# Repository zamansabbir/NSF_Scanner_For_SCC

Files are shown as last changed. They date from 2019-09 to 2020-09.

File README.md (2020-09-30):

#Firmware details presented in flow-chart
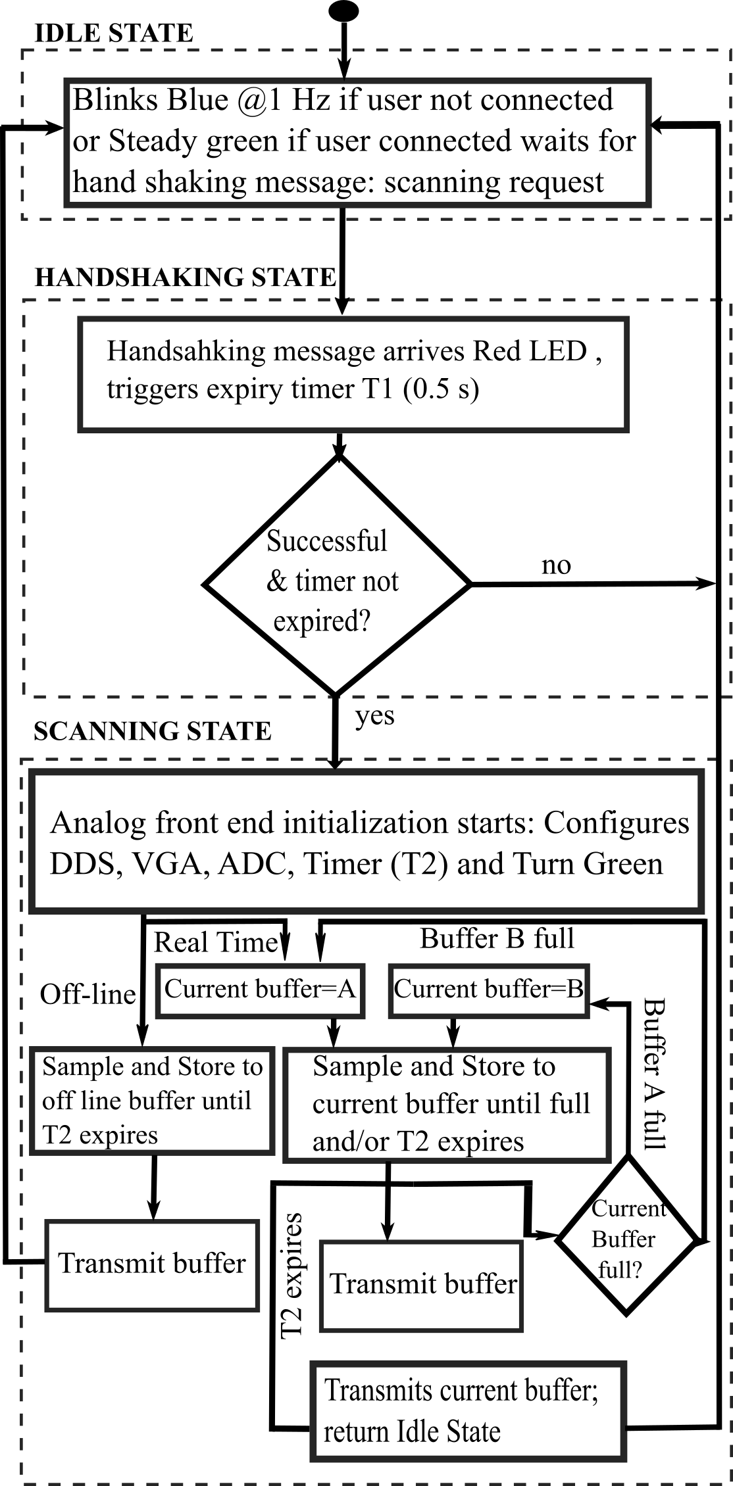
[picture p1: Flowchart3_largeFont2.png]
Flow chart of the Firmware Implemented


#Details of hand-shaking protocol implemented for the project: 
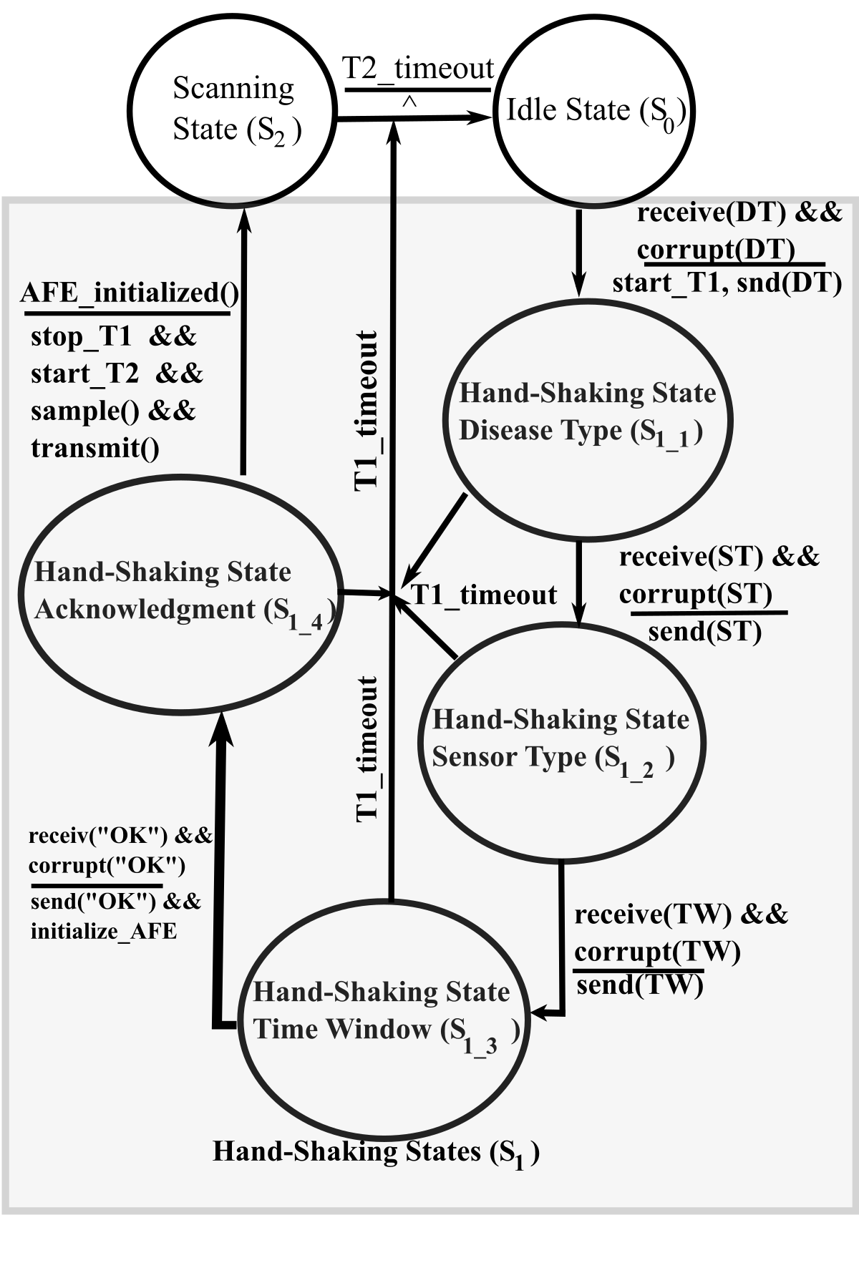
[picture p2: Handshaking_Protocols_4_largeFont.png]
FSM handshaking


.

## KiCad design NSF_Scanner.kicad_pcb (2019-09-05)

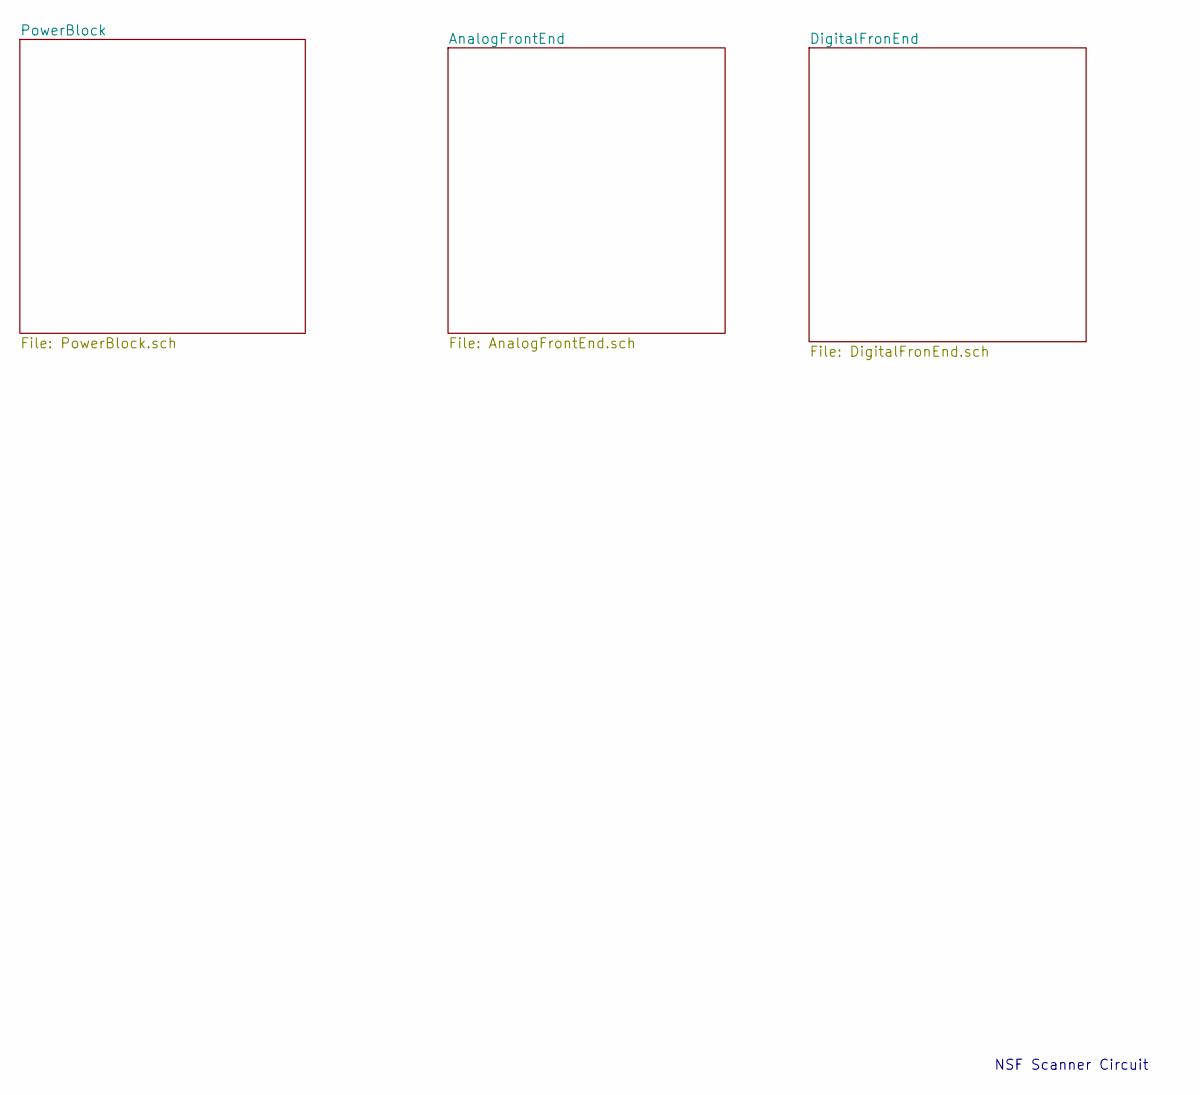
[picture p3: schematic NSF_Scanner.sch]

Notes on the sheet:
NSF Scanner Circuit

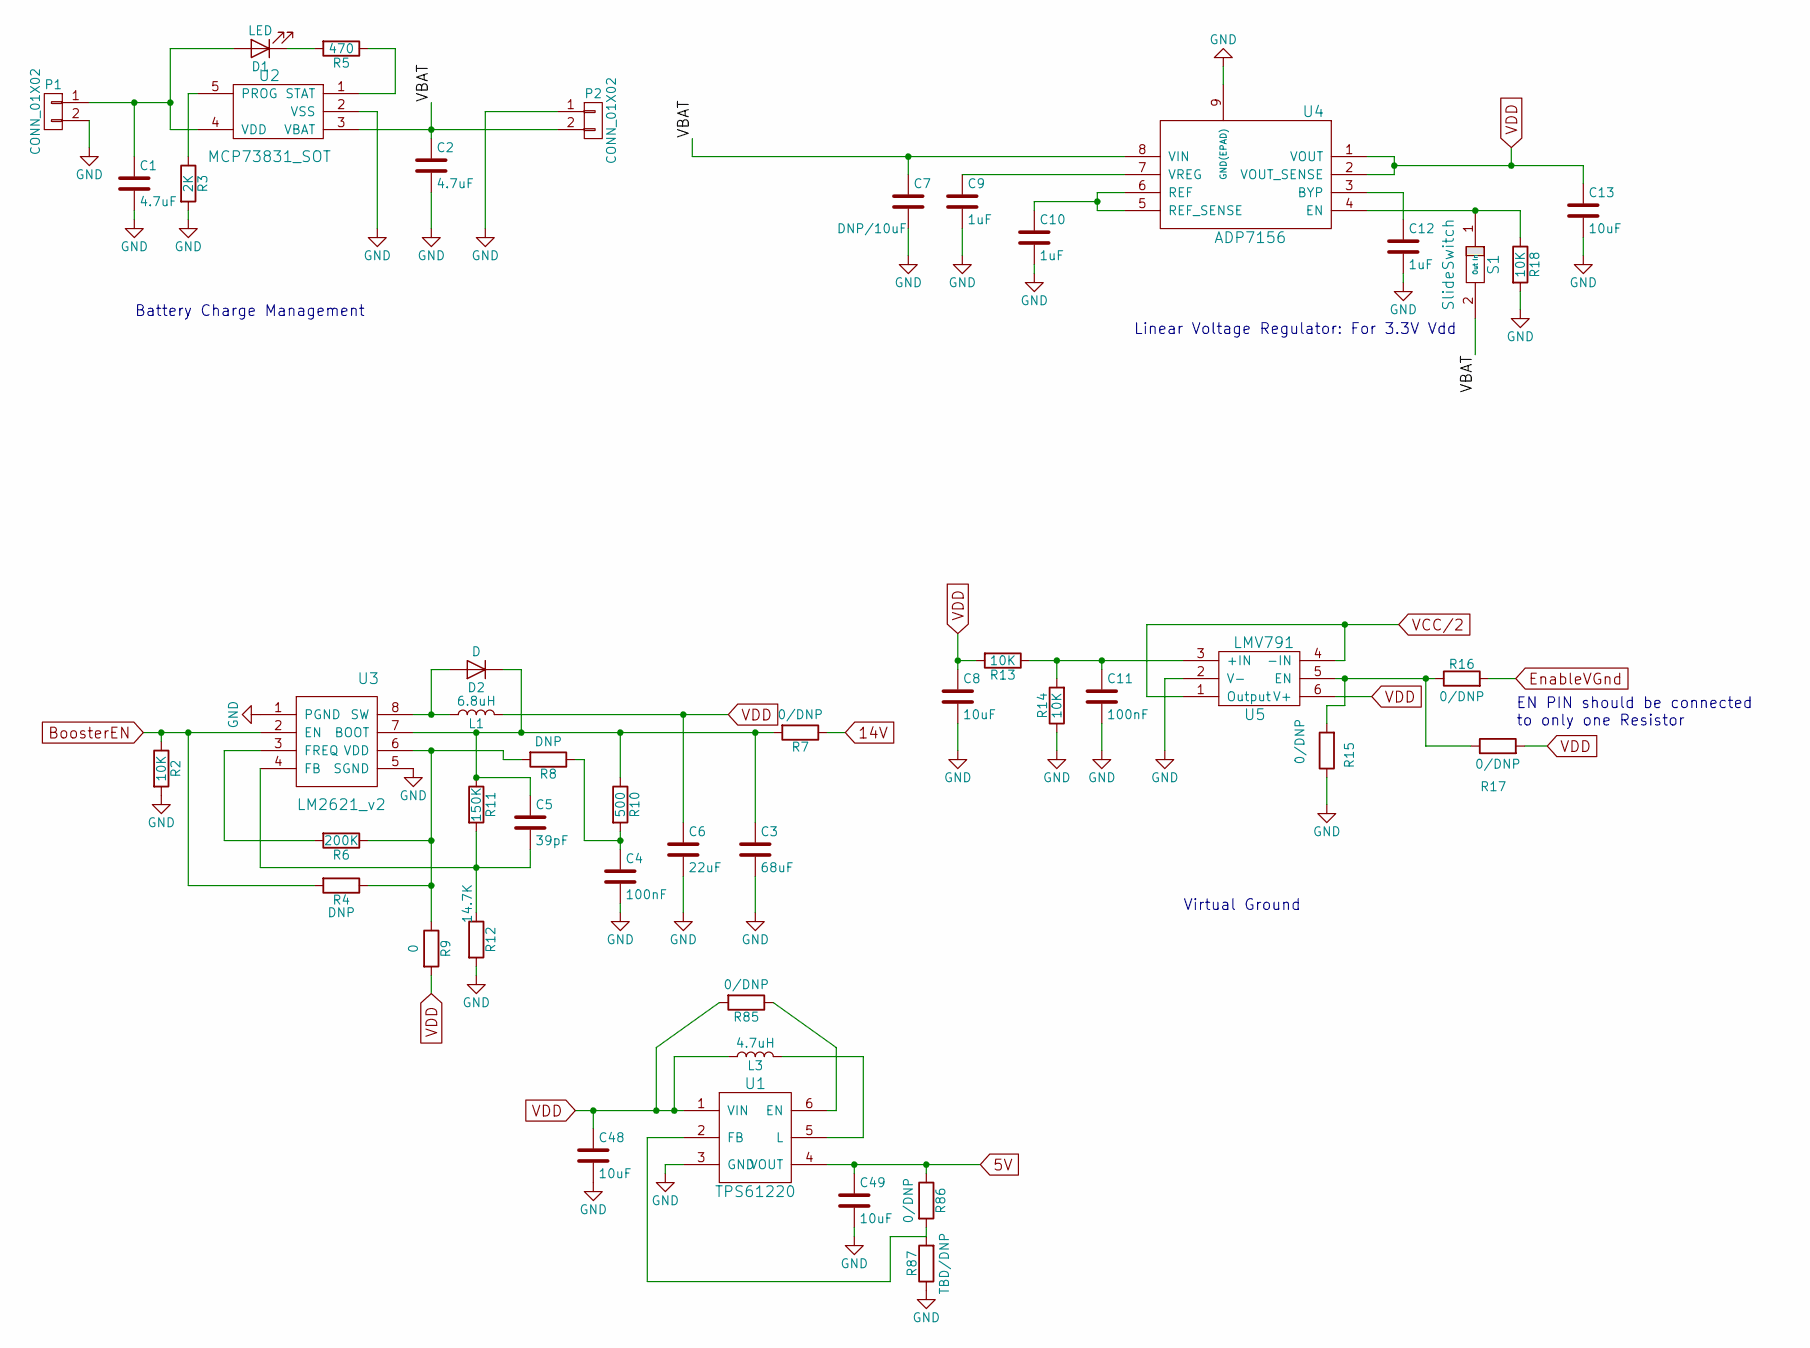
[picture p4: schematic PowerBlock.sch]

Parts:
C1, C2: 4.7uF; C_0603
C3: 68uF; C_1206
C4, C11: 100nF; C_0603
C5: 39pF; C_0603
C6: 22uF; C_0603
C7: DNP/10uF; C_0603
C8, C13, C48, C49: 10uF; C_0603
C9, C10, C12: 1uF; C_0603
D1: LED; LED_0603
D2: D; schottky_power_rectifier
L1: 6.8uH; L_0805_V2
L3: 4.7uH; 4.7uH_v2
P1: CONN_01X02; power_jack
P2: CONN_01X02; bat_con_v2
R2, R13, R14, R18: 10K; R_0603_HandSoldering
R3: 2K; R_0603_HandSoldering
R4, R8: DNP; R_0603_HandSoldering
R5: 470; R_0603_HandSoldering
R6: 200K; R_0603_HandSoldering
R7, R15, R16, R17, R85, R86: 0/DNP; R_0603_HandSoldering
R9: 0; R_0603_HandSoldering
R10: 500; R_0603_HandSoldering
R11: 150K; R_0603_HandSoldering
R12: 14.7K; R_0603_HandSoldering
R87: TBD/DNP; R_0603_HandSoldering
S1: SlideSwitch; SLIDE_SWITCH_V2
U1: TPS61220; TPS61222DCKR
U2: MCP73831_SOT; SOT-23-5_HandSoldering
U3: LM2621_v2
U4: ADP7156; ADP7156_v2
U5: LMV791; LMV791_v2

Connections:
5V: C49.1, R86.1, U1.4 (VOUT); also elsewhere on the board
14V: R7.1; also elsewhere on the board
/PowerBlock/VBAT: C2.1, C7.1, P2.2, S1.2 (Out), U2.3 (VBAT), U4.8 (VIN)
BoosterEN: R2.1, R4.2, U3.2 (EN); also elsewhere on the board
EnableVGnd: R16.2; also elsewhere on the board
GND: C1.2, C2.2, C3.2, C4.2, C6.2, C7.2, C8.2, C9.2, C10.2, C11.2, C12.2, C13.2, C48.2, C49.2, P1.2, P2.1, R2.2, R3.2, R12.2, R14.1, R15.1, R18.2, R87.1, U1.3 (GND), U2.2 (VSS), U3.1 (PGND), U3.5 (SGND), U4.9 (GND(EPAD)), U5.2 (V-); also elsewhere on the board
unnamed: C1.1, D1.2 (A), P1.1, U2.4 (VDD)
unnamed: C3.1, C5.1, D2.1 (K), R7.2, R10.1, R11.1, U3.7 (BOOT)
unnamed: C4.1, R8.1, R10.2
unnamed: C5.2, R11.2, R12.1, U3.4 (FB)
unnamed: C9.1, U4.7 (VREG)
unnamed: C10.1, U4.5 (REF_SENSE), U4.6 (REF)
unnamed: C11.1, R13.1, R14.2, U5.3 (+IN)
unnamed: C12.1, U4.3 (BYP)
unnamed: D1.1 (K), R5.2
unnamed: D2.2 (A), L1.1, U3.8 (SW)
unnamed: L3.2, U1.5 (L)
unnamed: R3.1, U2.5 (PROG)
unnamed: R4.1, R6.1, R8.2, R9.1, U3.6 (VDD)
unnamed: R5.1, U2.1 (STAT)
unnamed: R6.2, U3.3 (FREQ)
unnamed: R15.2, R16.1, R17.1, U5.5 (EN)
unnamed: R18.1, S1.1 (In), U4.4 (EN)
unnamed: R85.1, U1.6 (EN)
unnamed: R86.2, R87.2, U1.2 (FB)
VDD: C6.1, C8.1, C13.1, C48.1, L1.2, L3.1, R9.2, R13.2, R17.2, R85.2, U1.1 (VIN), U4.1 (VOUT), U4.2 (VOUT_SENSE), U5.6 (V+); also elsewhere on the board

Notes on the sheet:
Battery Charge Management
Linear Voltage Regulator: For 3.3V Vdd
EN PIN should be connected to only one Resistor
Virtual Ground

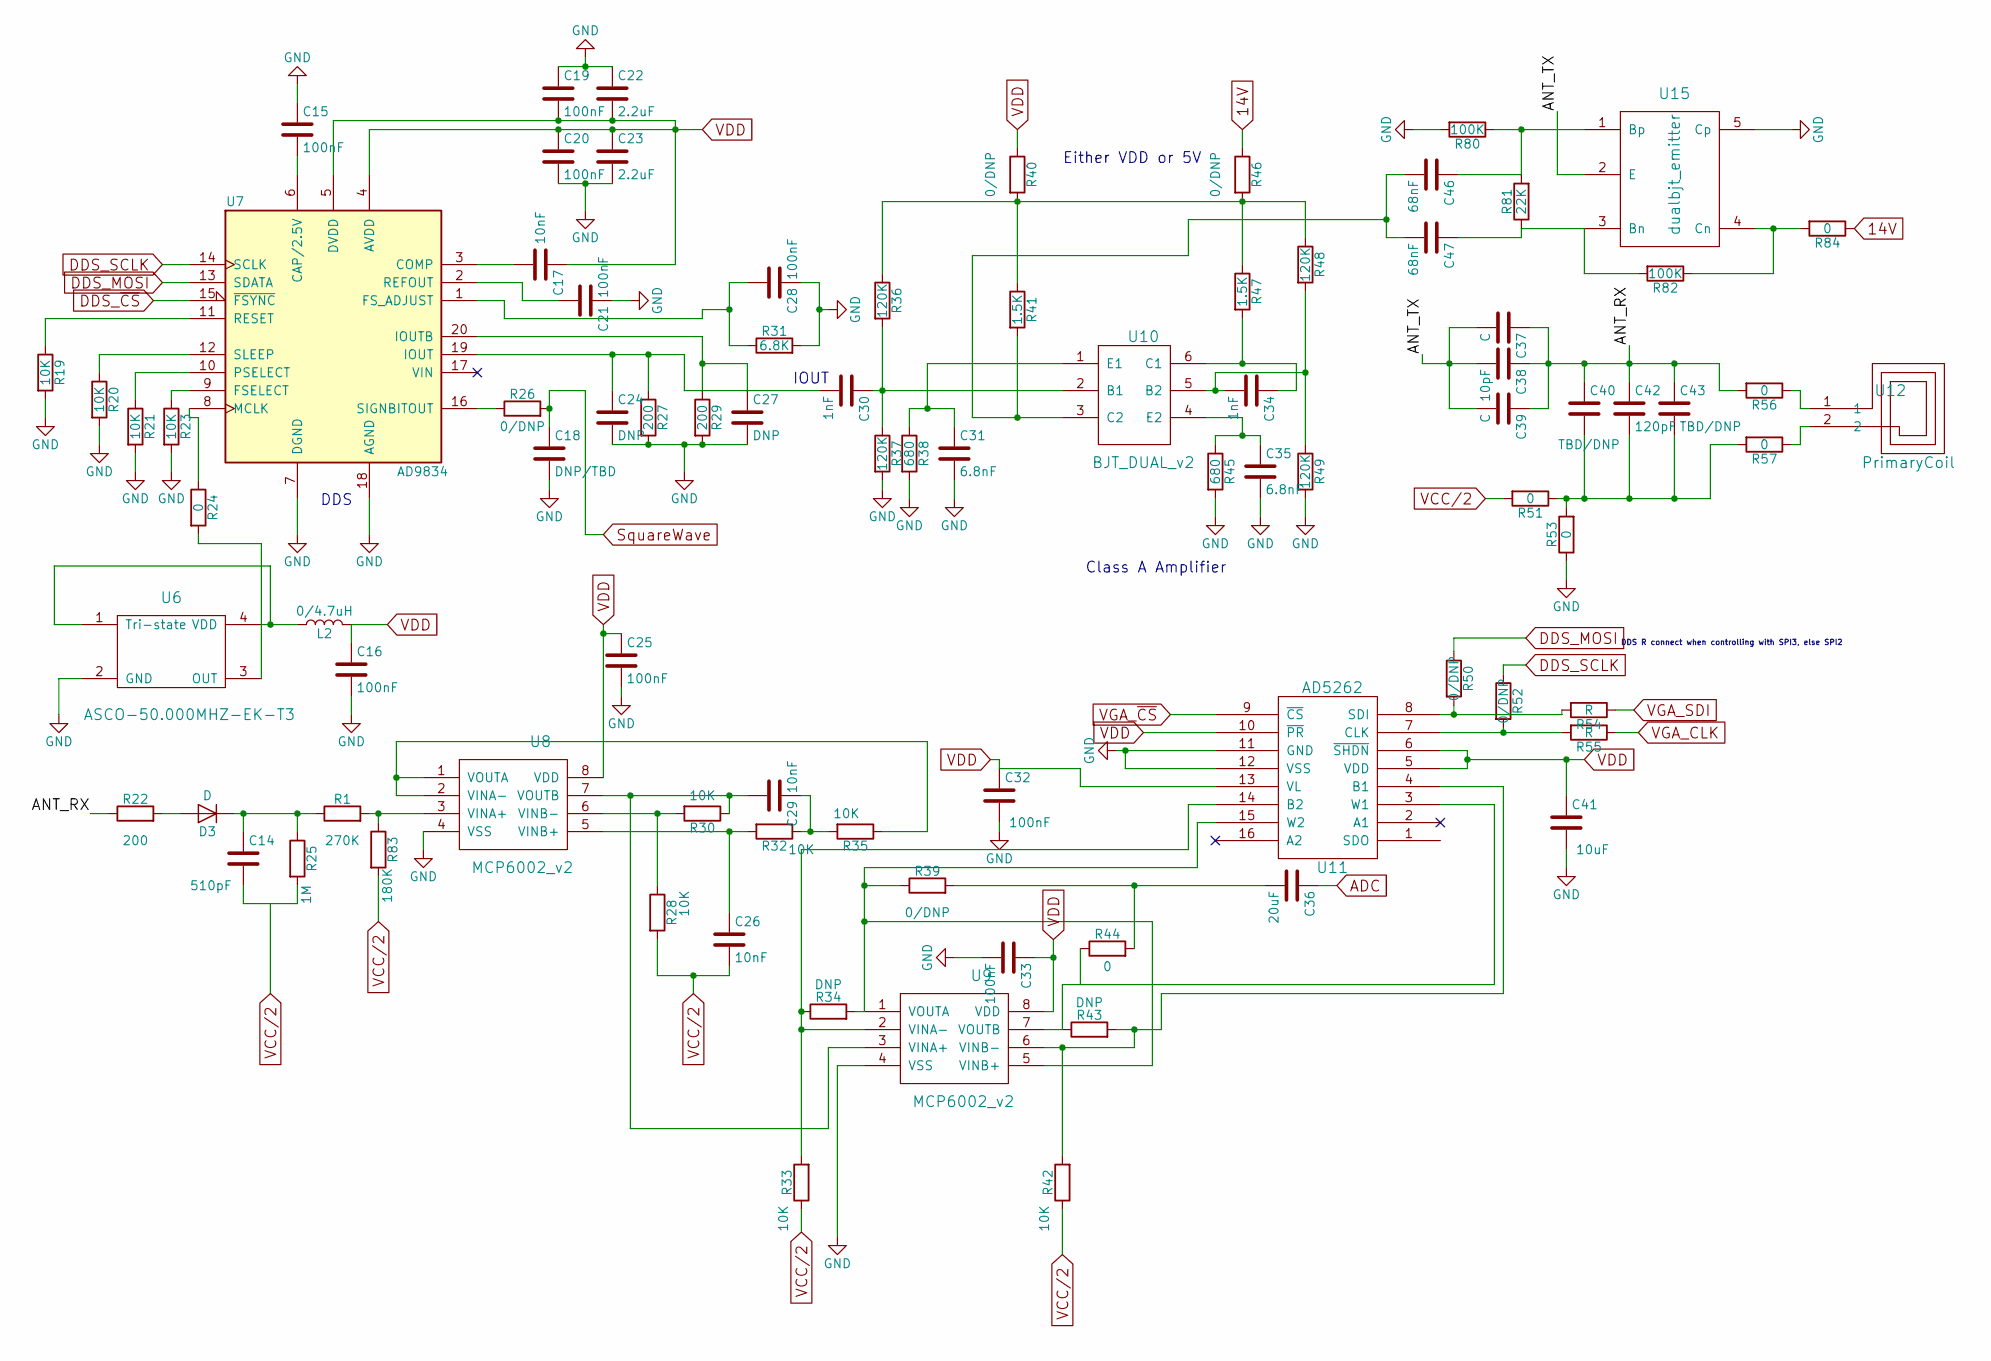
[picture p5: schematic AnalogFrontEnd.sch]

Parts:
C14: 510pF; C_0603
C15, C16, C19, C20, C21, C25, C28, C32, C33: 100nF; C_0603
C17, C26, C29: 10nF; C_0603
C18: DNP/TBD; C_0603
C22, C23: 2.2uF; C_0603
C24, C27: DNP; C_0603
C30, C34: 1nF; C_0603
C31, C35: 6.8nF; C_0603
C36: 20uF; C_0603
C37, C39: C; C_0603
C38: 10pF; C_0603
C40, C43: TBD/DNP; C_0603
C41: 10uF; C_0603
C42: 120pF; C_0603
C46, C47: 68nF; C_0603
D3: D; D_0603
L2: 0/4.7uH; 4.7uH_v2
R1: 270K; R_0603_HandSoldering
R19, R20, R21, R23, R28, R30, R32, R33, R35, R42: 10K; R_0603_HandSoldering
R22, R27, R29: 200; R_0603_HandSoldering
R24, R44, R51, R53, R56, R57, R84: 0; R_0603_HandSoldering
R25: 1M; R_0603_HandSoldering
R26, R39, R40, R46, R50, R52: 0/DNP; R_0603_HandSoldering
R31: 6.8K; R_0603_HandSoldering
R34, R43: DNP; R_0603_HandSoldering
R36, R37, R48, R49: 120K; R_0603_HandSoldering
R38, R45: 680; R_0603_HandSoldering
R41, R47: 1.5K; R_0603_HandSoldering
R54, R55: R; R_0603_HandSoldering
R80, R82: 100K; R_0603_HandSoldering
R81: 22K; R_0603_HandSoldering
R83: 180K; R_0603_HandSoldering
U6: ASCO-50.000MHZ-EK-T3; 50MHZ_OSCI
U7: AD9834; AD9834_v2
U8, U9: MCP6002_v2; mcp6002_s
U10: BJT_DUAL_v2; BJT_DUAL_V3
U11: AD5262; AD5262_v2
U12: PrimaryCoil; d13_v2
U15: dualbjt_emitter; SOT-23-5_HandSoldering

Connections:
14V: R46.1, R84.1; also elsewhere on the board
/AnalogFrontEnd/ANT_RX: C37.1, C38.1, C39.1, C40.1, C42.1, C43.1, R22.1, R56.2
/AnalogFrontEnd/ANT_TX: C37.2, C38.2, C39.2, U15.2 (E)
ADC: C36.1; also elsewhere on the board
DDS_MOSI: R50.1, U7.13 (SDATA); also elsewhere on the board
DDS_SCLK: R52.1, U7.14 (SCLK); also elsewhere on the board
DDS_~CS: U7.15 (~FSYNC); also elsewhere on the board
GND: C15.1, C16.2, C18.2, C19.1, C20.2, C21.1, C22.1, C23.2, C24.2, C25.2, C27.2, C28.1, C31.2, C32.2, C33.2, C35.2, C41.2, R19.2, R20.2, R21.2, R23.2, R27.2, R29.2, R31.2, R37.2, R38.2, R45.2, R49.2, R53.1, R80.2, U6.2 (GND), U7.7 (DGND), U7.18 (AGND), U8.4 (VSS), U9.4 (VSS), U11.11 (GND), U11.12 (VSS), U15.5 (Cp); also elsewhere on the board
unnamed: C14.1, D3.1 (K), R1.1, R25.1
unnamed: C15.2, U7.6 (CAP/2.5V)
unnamed: C17.2, U7.3 (COMP)
unnamed: C21.2, U7.2 (REFOUT)
unnamed: C24.1, C30.2, R27.1, U7.19 (IOUT)
unnamed: C26.1, R32.2, U8.5 (VINB+)
unnamed: C27.1, R29.1, U7.20 (IOUTB)
unnamed: C28.2, R31.1, U7.1 (FS_ADJUST)
unnamed: C29.1, R32.1, R35.2
unnamed: C29.2, R30.1, U8.7 (VOUTB), U9.3 (VINA+)
unnamed: C30.1, R36.2, R37.1, U10.2 (B1)
unnamed: C31.1, R38.1, U10.1 (E1)
unnamed: C34.1, R47.2, U10.6 (C1)
unnamed: C34.2, R48.2, R49.1, U10.5 (B2)
unnamed: C35.1, R45.1, U10.4 (E2)
unnamed: C36.2, R39.2, R44.2
unnamed: C40.2, C42.2, C43.2, R51.1, R53.2, R57.2
unnamed: C46.1, R80.1, R81.2, U15.1 (Bp)
unnamed: C46.2, C47.2, R41.2, U10.3 (C2)
unnamed: C47.1, R81.1, R82.2, U15.3 (Bn)
unnamed: D3.2 (A), R22.2
unnamed: L2.1, U6.1 (Tri-state), U6.4 (VDD)
unnamed: R1.2, R83.1, U8.3 (VINA+)
unnamed: R19.1, U7.11 (RESET)
unnamed: R20.1, U7.12 (SLEEP)
unnamed: R21.1, U7.10 (PSELECT)
unnamed: R23.1, U7.9 (FSELECT)
unnamed: R24.1, U7.8 (MCLK)
unnamed: R24.2, U6.3 (OUT)
unnamed: R26.1, U7.16 (SIGNBITOUT)
unnamed: R28.1, R30.2, U8.6 (VINB-)
unnamed: R33.2, R34.1, U9.2 (VINA-), U11.14 (B2)
unnamed: R34.2, R39.1, U9.1 (VOUTA), U9.5 (VINB+), U11.15 (W2)
unnamed: R35.1, U8.1 (VOUTA), U8.2 (VINA-)
unnamed: R36.1, R40.2, R41.1, R46.2, R47.1, R48.1
unnamed: R42.2, R43.2, U9.6 (VINB-), U11.4 (B1)
unnamed: R50.2, R54.2, U11.8 (SDI)
unnamed: R52.2, R55.2, U11.7 (CLK)
unnamed: R56.1, U12.1
unnamed: R57.1, U12.2
unnamed: R82.1, R84.2, U15.4 (Cn)
SquareWave: C18.1, R26.2
VDD: C16.1, C17.1, C19.2, C20.1, C22.2, C23.1, C25.1, C32.1, C33.1, C41.1, L2.2, R40.1, U7.4 (AVDD), U7.5 (DVDD), U8.8 (VDD), U9.8 (VDD), U11.5 (VDD), U11.6 (~SHDN), U11.10 (~PR), U11.13 (VL); also elsewhere on the board
VGA_CLK: R55.1; also elsewhere on the board
VGA_SDI: R54.1; also elsewhere on the board
VGA_~CS: U11.9 (~CS); also elsewhere on the board

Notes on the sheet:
IOUT
DDS
Either VDD or 5V
Class A Amplifier
DDS R connect when controlling with SPI3, else SPI2

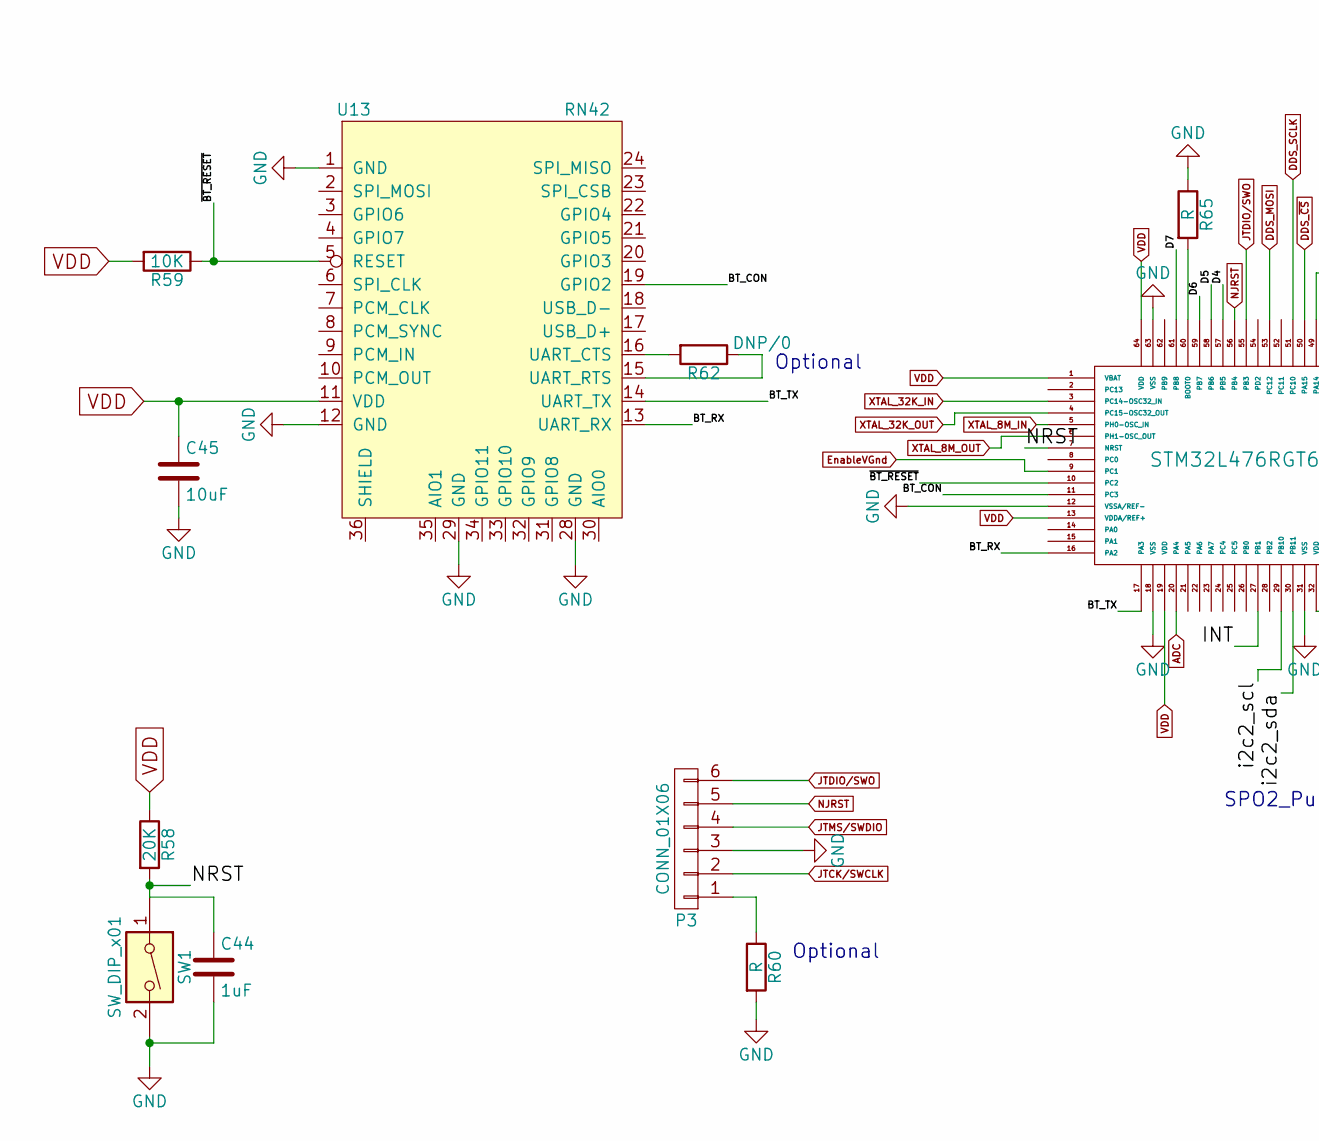
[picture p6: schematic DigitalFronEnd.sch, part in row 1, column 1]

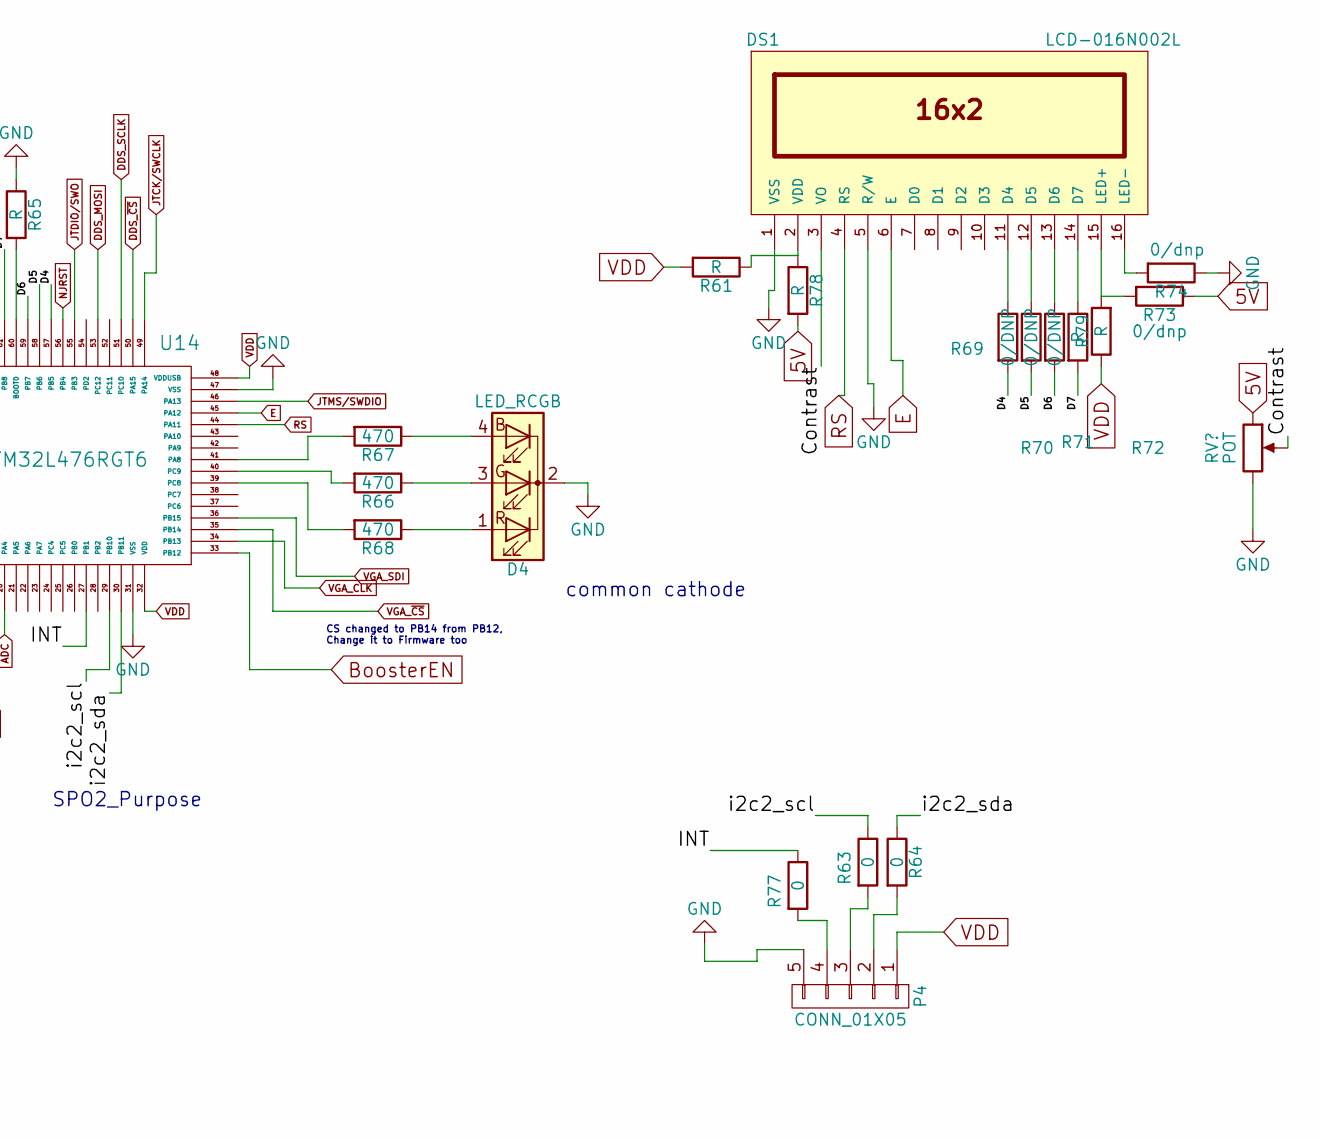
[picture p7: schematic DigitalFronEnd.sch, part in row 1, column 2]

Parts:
C44: 1uF; C_0603
C45: 10uF; C_0603
D4: LED_RCGB; rgb_LED_V3
DS1: LCD-016N002L; LCD_16X2_V2
P3: CONN_01X06; ST_Link_Programmer
P4: CONN_01X05; SPO2_v2
R58: 20K; R_0603_HandSoldering
R59: 10K; R_0603_HandSoldering
R60, R61, R65, R72, R78, R79: R; R_0603_HandSoldering
R62: DNP/0; R_0603_HandSoldering
R63, R64, R77: 0; R_0603_HandSoldering
R66, R67, R68: 470; R_0603_HandSoldering
R69, R70, R71: 0/DNP; R_0603_HandSoldering
R73, R74: 0/dnp; R_0603_HandSoldering
SW1: SW_DIP_x01; SPST_v2
U13: RN42; RN42_v2
U14: STM32L476RGT6; STM32L476_LQFP64

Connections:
5V: R73.1, R78.2; also elsewhere on the board
/DigitalFronEnd/BT_CON: U13.19 (GPIO2), U14.11 (PC3)
/DigitalFronEnd/BT_RX: U13.13 (UART_RX), U14.16 (PA2)
/DigitalFronEnd/BT_TX: U13.14 (UART_TX), U14.17 (PA3)
/DigitalFronEnd/Contrast: DS1.3 (VO); also elsewhere on the board
/DigitalFronEnd/D4: R69.2, U14.57 (PB5)
/DigitalFronEnd/D5: R70.2, U14.58 (PB6)
/DigitalFronEnd/D6: R71.2, U14.59 (PB7)
/DigitalFronEnd/D7: R72.2, U14.61 (PB8)
/DigitalFronEnd/INT: R77.1, U14.27 (PB1)
/DigitalFronEnd/NRST: C44.1, R58.2, SW1.1, U14.7 (NRST)
/DigitalFronEnd/i2c2_scl: R63.1, U14.29 (PB10)
/DigitalFronEnd/i2c2_sda: R64.1, U14.30 (PB11)
/DigitalFronEnd/~BT_RESET: R59.1, U13.5 (RESET), U14.10 (PC2)
ADC: U14.20 (PA4); also elsewhere on the board
BoosterEN: U14.33 (PB12); also elsewhere on the board
DDS_MOSI: U14.53 (PC12); also elsewhere on the board
DDS_SCLK: U14.51 (PC10); also elsewhere on the board
DDS_~CS: U14.50 (PA15); also elsewhere on the board
E: DS1.6 (E), U14.45 (PA12)
EnableVGnd: U14.9 (PC1); also elsewhere on the board
GND: C44.2, C45.2, D4.2 (K), DS1.1 (VSS), DS1.5 (R/W), P3.3, P4.5, R60.2, R65.1, R74.1, SW1.2, U13.1 (GND), U13.12 (GND), U13.28 (GND), U13.29 (GND), U14.12 (VSSA/REF-), U14.18 (VSS), U14.31 (VSS), U14.47 (VSS), U14.63 (VSS); also elsewhere on the board
JTCK/SWCLK: P3.2, U14.49 (PA14)
JTDIO/SWO: P3.6, U14.55 (PB3)
JTMS/SWDIO: P3.4, U14.46 (PA13)
NJRST: P3.5, U14.56 (PB4)
unnamed: D4.1 (RA), R68.1
unnamed: D4.3 (GA), R66.1
unnamed: D4.4 (BA), R67.1
unnamed: DS1.2 (VDD), R61.1, R78.1
unnamed: DS1.11 (D4), R69.1
unnamed: DS1.12 (D5), R70.1
unnamed: DS1.13 (D6), R71.1
unnamed: DS1.14 (D7), R72.1
unnamed: DS1.15 (LED+), R73.2, R79.2
unnamed: DS1.16 (LED-), R74.2
unnamed: P3.1, R60.1
unnamed: P4.2, R64.2
unnamed: P4.3, R63.2
unnamed: P4.4, R77.2
unnamed: R62.1, U13.15 (UART_RTS)
unnamed: R62.2, U13.16 (UART_CTS)
unnamed: R65.2, U14.60 (BOOT0)
unnamed: R66.2, U14.40 (PC9)
unnamed: R67.2, U14.41 (PA8)
unnamed: R68.2, U14.39 (PC8)
RS: DS1.4 (RS), U14.44 (PA11)
VDD: C45.1, P4.1, R58.1, R59.2, R61.2, R79.1, U13.11 (VDD), U14.1 (VBAT), U14.13 (VDDA/REF+), U14.19 (VDD), U14.32 (VDD), U14.48 (VDDUSB), U14.64 (VDD); also elsewhere on the board
VGA_CLK: U14.34 (PB13); also elsewhere on the board
VGA_SDI: U14.36 (PB15); also elsewhere on the board
VGA_~CS: U14.35 (PB14); also elsewhere on the board
XTAL_8M_IN: U14.5 (PH0-OSC_IN)
XTAL_8M_OUT: U14.6 (PH1-OSC_OUT)
XTAL_32K_IN: U14.3 (PC14-OSC32_IN)
XTAL_32K_OUT: U14.4 (PC15-OSC32_OUT)

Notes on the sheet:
Optional
common cathode
SPO2_Purpose
CS changed to PB14 from PB12, Change it to Firmware too

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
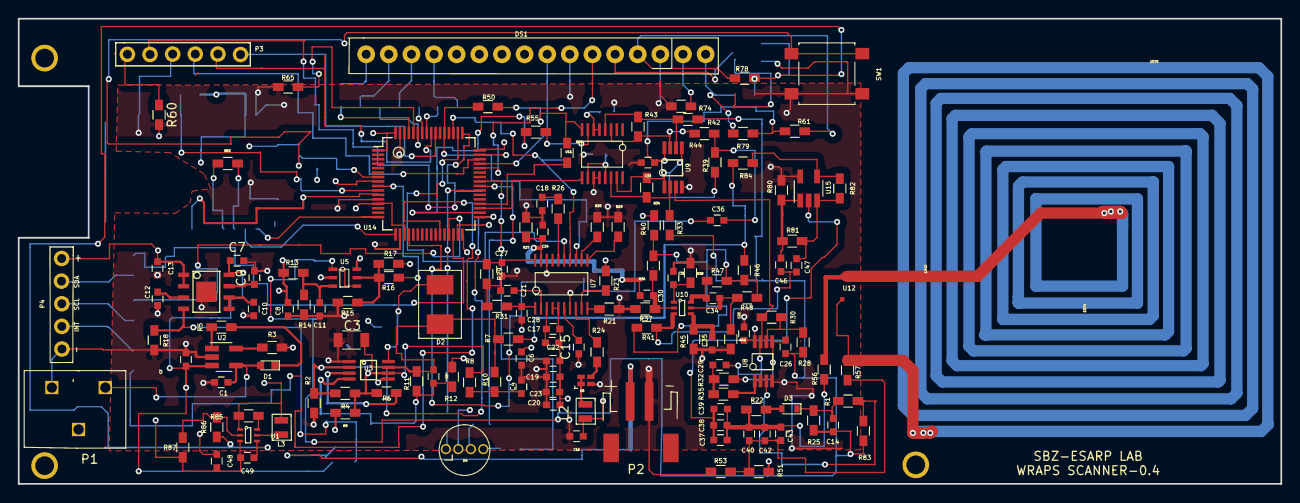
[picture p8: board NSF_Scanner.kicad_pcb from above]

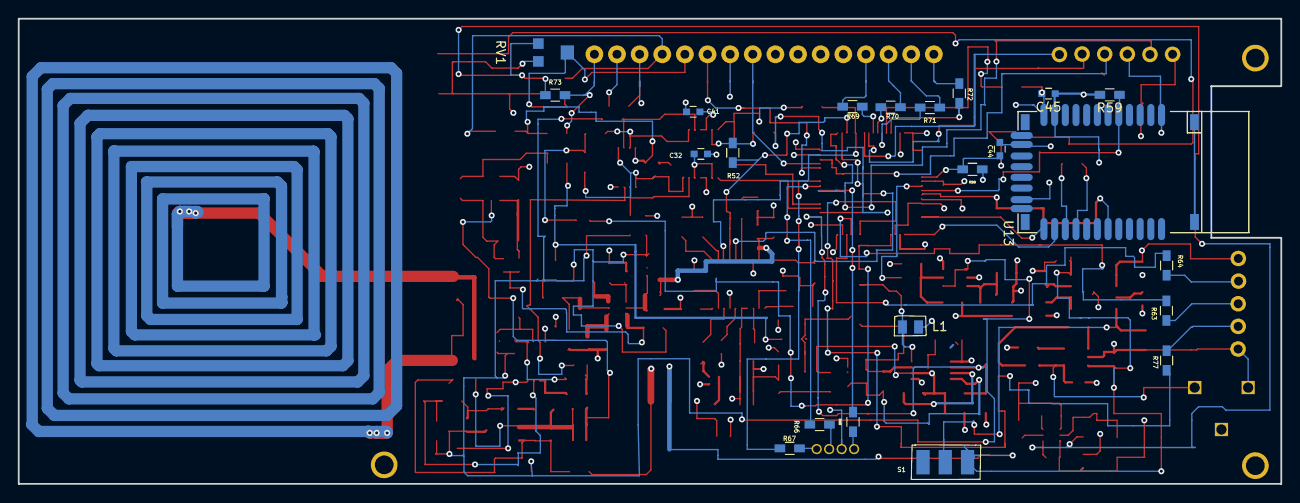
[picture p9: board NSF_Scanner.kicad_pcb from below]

Board: 4 copper layers, 141.7 x 52.2 mm, 164 parts (22 on the bottom side), 118 nets.

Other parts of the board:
RV1: POT; TC_33_pot

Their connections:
5V: RV1.1; also elsewhere on the board
/DigitalFronEnd/Contrast: RV1.2; also elsewhere on the board
GND: RV1.3; also elsewhere on the board

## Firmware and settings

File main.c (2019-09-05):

/**
  ******************************************************************************
  * File Name          : main.c
  * Description        : Main program body
  ******************************************************************************
  *
  * COPYRIGHT(c) 2018 STMicroelectronics
  *
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
  ******************************************************************************
  */
/* Includes ------------------------------------------------------------------*/
#include "stm32l4xx_hal.h"

/* USER CODE BEGIN Includes */

#include "scanner.h"
#include "scanner_interrupt_routine.h"
#include <stdlib.h>
#include <string.h>
/* USER CODE END Includes */

ADC_HandleTypeDef hadc1;

SPI_HandleTypeDef hspi2;
SPI_HandleTypeDef hspi3;

TIM_HandleTypeDef htim2;
TIM_HandleTypeDef htim3;
TIM_HandleTypeDef htim4;
TIM_HandleTypeDef htim5;

UART_HandleTypeDef huart2;

/* USER CODE BEGIN PV */


/* USER CODE END PV */

void SystemClock_Config(void);
void Error_Handler(void);
static void MX_GPIO_Init(void);
static void MX_SPI3_Init(void);
static void MX_USART2_UART_Init(void);
static void MX_ADC1_Init(void);
static void MX_SPI2_Init(void);
static void MX_TIM2_Init(void);
static void MX_TIM3_Init(void);
static void MX_TIM5_Init(void);

/* USER CODE BEGIN PFP */



/* USER CODE END PFP */

int main(void)
{

  /* MCU Configuration----------------------------------------------------------*/

  /* Reset of all peripherals, Initializes the Flash interface and the Systick. */
  HAL_Init();

  /* Configure the system clock */
  SystemClock_Config();

  /* Initialize all configured peripherals */
  MX_GPIO_Init();
  MX_SPI3_Init();
  MX_USART2_UART_Init();
  MX_ADC1_Init();
  MX_SPI2_Init();
  MX_TIM2_Init();
  MX_TIM3_Init();
  MX_TIM5_Init();

  /* USER CODE BEGIN 2 */
	//generateSignal(4650000);

setResistor(1,R1);
setResistor(0,R2);

	//setResistor(1,32);
	//setResistor(0,8);
//int f[]={11150000,11155000,11150000}
putDDSToSleep();
HAL_Delay(10);
//__HAL_RCC_ADC_CLK_DISABLE();
setToFiveHz(); //LED Blinking
HAL_UART_Receive_IT(&huart2,Rx_data,1);
//generateSignal(10150000);
//HAL_Delay(3000);
//generateSignal(12150000);


  /* USER CODE END 2 */

  /* Infinite loop */
  /* USER CODE BEGIN WHILE */
  while (1)
  {
		if(!handshaking){
		if(HAL_GPIO_ReadPin(GPIOC,GPIO_PIN_3)){
	//			resetFiveHz();
			showScannerConnected();
			}else{
				//resetSteady();
				//setToFiveHz();
				showScannerDisconnected();
		}}
	
	//	transmitBuffer();
	
		if(resetWindowDone==1){
		putDDSToSleep();
		resetWindowDone=0;
		}
		
  /* USER CODE END WHILE */

  /* USER CODE BEGIN 3 */

		
  }
  /* USER CODE END 3 */

}

/** System Clock Configuration
*/
void SystemClock_Config(void)
{

  RCC_OscInitTypeDef RCC_OscInitStruct;
  RCC_ClkInitTypeDef RCC_ClkInitStruct;
  RCC_PeriphCLKInitTypeDef PeriphClkInit;

  RCC_OscInitStruct.OscillatorType = RCC_OSCILLATORTYPE_HSI;
  RCC_OscInitStruct.HSIState = RCC_HSI_ON;
  RCC_OscInitStruct.HSICalibrationValue = 16;
  RCC_OscInitStruct.PLL.PLLState = RCC_PLL_NONE;
  if (HAL_RCC_OscConfig(&RCC_OscInitStruct) != HAL_OK)
  {
    Error_Handler();
  }

  RCC_ClkInitStruct.ClockType = RCC_CLOCKTYPE_HCLK|RCC_CLOCKTYPE_SYSCLK
                              |RCC_CLOCKTYPE_PCLK1|RCC_CLOCKTYPE_PCLK2;
  RCC_ClkInitStruct.SYSCLKSource = RCC_SYSCLKSOURCE_HSI;
  RCC_ClkInitStruct.AHBCLKDivider = RCC_SYSCLK_DIV1;
  RCC_ClkInitStruct.APB1CLKDivider = RCC_HCLK_DIV1;
  RCC_ClkInitStruct.APB2CLKDivider = RCC_HCLK_DIV1;
  if (HAL_RCC_ClockConfig(&RCC_ClkInitStruct, FLASH_LATENCY_0) != HAL_OK)
  {
    Error_Handler();
  }

  PeriphClkInit.PeriphClockSelection = RCC_PERIPHCLK_USART2|RCC_PERIPHCLK_ADC;
  PeriphClkInit.Usart2ClockSelection = RCC_USART2CLKSOURCE_HSI;
  PeriphClkInit.AdcClockSelection = RCC_ADCCLKSOURCE_PLLSAI1;
  PeriphClkInit.PLLSAI1.PLLSAI1Source = RCC_PLLSOURCE_HSI;
  PeriphClkInit.PLLSAI1.PLLSAI1M = 1;
  PeriphClkInit.PLLSAI1.PLLSAI1N = 8;
  PeriphClkInit.PLLSAI1.PLLSAI1P = RCC_PLLP_DIV7;
  PeriphClkInit.PLLSAI1.PLLSAI1Q = RCC_PLLQ_DIV2;
  PeriphClkInit.PLLSAI1.PLLSAI1R = RCC_PLLR_DIV8;
  PeriphClkInit.PLLSAI1.PLLSAI1ClockOut = RCC_PLLSAI1_ADC1CLK;
  if (HAL_RCCEx_PeriphCLKConfig(&PeriphClkInit) != HAL_OK)
  {
    Error_Handler();
  }

  __HAL_RCC_PWR_CLK_ENABLE();

  if (HAL_PWREx_ControlVoltageScaling(PWR_REGULATOR_VOLTAGE_SCALE1) != HAL_OK)
  {
    Error_Handler();
  }

  HAL_SYSTICK_Config(HAL_RCC_GetHCLKFreq()/1000);

  HAL_SYSTICK_CLKSourceConfig(SYSTICK_CLKSOURCE_HCLK);

  /* SysTick_IRQn interrupt configuration */
  HAL_NVIC_SetPriority(SysTick_IRQn, 0, 0);
}

/* ADC1 init function */
static void MX_ADC1_Init(void)
{

  ADC_MultiModeTypeDef multimode;
  ADC_ChannelConfTypeDef sConfig;

    /**Common config 
    */
  hadc1.Instance = ADC1;
  hadc1.Init.ClockPrescaler = ADC_CLOCK_ASYNC_DIV1;
  hadc1.Init.Resolution = ADC_RESOLUTION_12B;
  hadc1.Init.DataAlign = ADC_DATAALIGN_RIGHT;
  hadc1.Init.ScanConvMode = ADC_SCAN_DISABLE;
  hadc1.Init.EOCSelection = ADC_EOC_SINGLE_CONV;
  hadc1.Init.LowPowerAutoWait = DISABLE;
  hadc1.Init.ContinuousConvMode = DISABLE;
  hadc1.Init.NbrOfConversion = 1;
  hadc1.Init.DiscontinuousConvMode = DISABLE;
  hadc1.Init.ExternalTrigConv = ADC_SOFTWARE_START;
  hadc1.Init.ExternalTrigConvEdge = ADC_EXTERNALTRIGCONVEDGE_NONE;
  hadc1.Init.DMAContinuousRequests = DISABLE;
  hadc1.Init.Overrun = ADC_OVR_DATA_PRESERVED;
  hadc1.Init.OversamplingMode = DISABLE;
  if (HAL_ADC_Init(&hadc1) != HAL_OK)
  {
    Error_Handler();
  }

    /**Configure the ADC multi-mode 
    */
  multimode.Mode = ADC_MODE_INDEPENDENT;
  if (HAL_ADCEx_MultiModeConfigChannel(&hadc1, &multimode) != HAL_OK)
  {
    Error_Handler();
  }

    /**Configure Regular Channel 
    */
  sConfig.Channel = ADC_CHANNEL_9;
  sConfig.Rank = 1;
  sConfig.SamplingTime = ADC_SAMPLETIME_2CYCLES_5;
  sConfig.SingleDiff = ADC_SINGLE_ENDED;
  sConfig.OffsetNumber = ADC_OFFSET_NONE;
  sConfig.Offset = 0;
  if (HAL_ADC_ConfigChannel(&hadc1, &sConfig) != HAL_OK)
  {
    Error_Handler();
  }

}

/* SPI2 init function */
static void MX_SPI2_Init(void)
{

  hspi2.Instance = SPI2;
  hspi2.Init.Mode = SPI_MODE_MASTER;
  hspi2.Init.Direction = SPI_DIRECTION_2LINES;
  hspi2.Init.DataSize = SPI_DATASIZE_8BIT;
  hspi2.Init.CLKPolarity = SPI_POLARITY_LOW;
  hspi2.Init.CLKPhase = SPI_PHASE_1EDGE;
  hspi2.Init.NSS = SPI_NSS_SOFT;
  hspi2.Init.BaudRatePrescaler = SPI_BAUDRATEPRESCALER_4;
  hspi2.Init.FirstBit = SPI_FIRSTBIT_MSB;
  hspi2.Init.TIMode = SPI_TIMODE_DISABLE;
  hspi2.Init.CRCCalculation = SPI_CRCCALCULATION_DISABLE;
  hspi2.Init.CRCPolynomial = 7;
  hspi2.Init.CRCLength = SPI_CRC_LENGTH_DATASIZE;
  hspi2.Init.NSSPMode = SPI_NSS_PULSE_ENABLE;
  if (HAL_SPI_Init(&hspi2) != HAL_OK)
  {
    Error_Handler();
  }

}

/* SPI3 init function */
static void MX_SPI3_Init(void)
{

  hspi3.Instance = SPI3;
  hspi3.Init.Mode = SPI_MODE_MASTER;
  hspi3.Init.Direction = SPI_DIRECTION_2LINES;
  hspi3.Init.DataSize = SPI_DATASIZE_8BIT;
  hspi3.Init.CLKPolarity = SPI_POLARITY_HIGH;
  hspi3.Init.CLKPhase = SPI_PHASE_1EDGE;
  hspi3.Init.NSS = SPI_NSS_SOFT;
  hspi3.Init.BaudRatePrescaler = SPI_BAUDRATEPRESCALER_2;
  hspi3.Init.FirstBit = SPI_FIRSTBIT_MSB;
  hspi3.Init.TIMode = SPI_TIMODE_DISABLE;
  hspi3.Init.CRCCalculation = SPI_CRCCALCULATION_DISABLE;
  hspi3.Init.CRCPolynomial = 7;
  hspi3.Init.CRCLength = SPI_CRC_LENGTH_DATASIZE;
  hspi3.Init.NSSPMode = SPI_NSS_PULSE_ENABLE;
  if (HAL_SPI_Init(&hspi3) != HAL_OK)
  {
    Error_Handler();
  }

}

/* TIM2 init function */
static void MX_TIM2_Init(void)
{

  TIM_ClockConfigTypeDef sClockSourceConfig;
  TIM_MasterConfigTypeDef sMasterConfig;

  htim2.Instance = TIM2;
  htim2.Init.Prescaler = 16;
  htim2.Init.CounterMode = TIM_COUNTERMODE_UP;
  htim2.Init.Period = 93;
  htim2.Init.ClockDivision = TIM_CLOCKDIVISION_DIV1;
  if (HAL_TIM_Base_Init(&htim2) != HAL_OK)
  {
    Error_Handler();
  }

  sClockSourceConfig.ClockSource = TIM_CLOCKSOURCE_INTERNAL;
  if (HAL_TIM_ConfigClockSource(&htim2, &sClockSourceConfig) != HAL_OK)
  {
    Error_Handler();
  }

  sMasterConfig.MasterOutputTrigger = TIM_TRGO_RESET;
  sMasterConfig.MasterSlaveMode = TIM_MASTERSLAVEMODE_DISABLE;
  if (HAL_TIMEx_MasterConfigSynchronization(&htim2, &sMasterConfig) != HAL_OK)
  {
    Error_Handler();
  }

}

/* TIM3 init function */
static void MX_TIM3_Init(void)
{

  TIM_ClockConfigTypeDef sClockSourceConfig;
  TIM_MasterConfigTypeDef sMasterConfig;

  htim3.Instance = TIM3;
  htim3.Init.Prescaler = 16000;
  htim3.Init.CounterMode = TIM_COUNTERMODE_UP;
  htim3.Init.Period = 99;
  htim3.Init.ClockDivision = TIM_CLOCKDIVISION_DIV1;
  if (HAL_TIM_Base_Init(&htim3) != HAL_OK)
  {
    Error_Handler();
  }

  sClockSourceConfig.ClockSource = TIM_CLOCKSOURCE_INTERNAL;
  if (HAL_TIM_ConfigClockSource(&htim3, &sClockSourceConfig) != HAL_OK)
  {
    Error_Handler();
  }

  sMasterConfig.MasterOutputTrigger = TIM_TRGO_RESET;
  sMasterConfig.MasterSlaveMode = TIM_MASTERSLAVEMODE_DISABLE;
  if (HAL_TIMEx_MasterConfigSynchronization(&htim3, &sMasterConfig) != HAL_OK)
  {
    Error_Handler();
  }

}

/* TIM4 init function */
static void MX_TIM4_Init(void)
{

  TIM_ClockConfigTypeDef sClockSourceConfig;
  TIM_MasterConfigTypeDef sMasterConfig;

  htim4.Instance = TIM4;
  htim4.Init.Prescaler = 16000;
  htim4.Init.CounterMode = TIM_COUNTERMODE_UP;
  htim4.Init.Period = 99;
  htim4.Init.ClockDivision = TIM_CLOCKDIVISION_DIV1;
  if (HAL_TIM_Base_Init(&htim4) != HAL_OK)
  {
    Error_Handler();
  }

  sClockSourceConfig.ClockSource = TIM_CLOCKSOURCE_INTERNAL;
  if (HAL_TIM_ConfigClockSource(&htim4, &sClockSourceConfig) != HAL_OK)
  {
    Error_Handler();
  }

  sMasterConfig.MasterOutputTrigger = TIM_TRGO_RESET;
  sMasterConfig.MasterSlaveMode = TIM_MASTERSLAVEMODE_DISABLE;
  if (HAL_TIMEx_MasterConfigSynchronization(&htim4, &sMasterConfig) != HAL_OK)
  {
    Error_Handler();
  }

}

/* TIM5 init function */
static void MX_TIM5_Init(void)
{

  TIM_ClockConfigTypeDef sClockSourceConfig;
  TIM_MasterConfigTypeDef sMasterConfig;

  htim5.Instance = TIM5;
  htim5.Init.Prescaler = 16000;
  htim5.Init.CounterMode = TIM_COUNTERMODE_UP;
  htim5.Init.Period = 499;
  htim5.Init.ClockDivision = TIM_CLOCKDIVISION_DIV1;
  if (HAL_TIM_Base_Init(&htim5) != HAL_OK)
  {
    Error_Handler();
  }

  sClockSourceConfig.ClockSource = TIM_CLOCKSOURCE_INTERNAL;
  if (HAL_TIM_ConfigClockSource(&htim5, &sClockSourceConfig) != HAL_OK)
  {
    Error_Handler();
  }

  sMasterConfig.MasterOutputTrigger = TIM_TRGO_RESET;
  sMasterConfig.MasterSlaveMode = TIM_MASTERSLAVEMODE_DISABLE;
  if (HAL_TIMEx_MasterConfigSynchronization(&htim5, &sMasterConfig) != HAL_OK)
  {
    Error_Handler();
  }

}

/* USART2 init function */
static void MX_USART2_UART_Init(void)
{

  huart2.Instance = USART2;
  huart2.Init.BaudRate = 115200;
  huart2.Init.WordLength = UART_WORDLENGTH_8B;
  huart2.Init.StopBits = UART_STOPBITS_1;
  huart2.Init.Parity = UART_PARITY_NONE;
  huart2.Init.Mode = UART_MODE_TX_RX;
  huart2.Init.HwFlowCtl = UART_HWCONTROL_NONE;
  huart2.Init.OverSampling = UART_OVERSAMPLING_16;
  huart2.Init.OneBitSampling = UART_ONE_BIT_SAMPLE_DISABLE;
  huart2.AdvancedInit.AdvFeatureInit = UART_ADVFEATURE_NO_INIT;
  if (HAL_UART_Init(&huart2) != HAL_OK)
  {
    Error_Handler();
  }

}

/** Configure pins as 
        * Analog 
        * Input 
        * Output
        * EVENT_OUT
        * EXTI
*/
static void MX_GPIO_Init(void)
{

  GPIO_InitTypeDef GPIO_InitStruct;

  /* GPIO Ports Clock Enable */
  __HAL_RCC_GPIOC_CLK_ENABLE();
  __HAL_RCC_GPIOA_CLK_ENABLE();
  __HAL_RCC_GPIOB_CLK_ENABLE();

  /*Configure GPIO pins : PC0 PC3 */
  GPIO_InitStruct.Pin = GPIO_PIN_0|GPIO_PIN_3;
  GPIO_InitStruct.Mode = GPIO_MODE_INPUT;
  GPIO_InitStruct.Pull = GPIO_NOPULL;
  HAL_GPIO_Init(GPIOC, &GPIO_InitStruct);

  /*Configure GPIO pins : PC2 PC8 PC9 */
  GPIO_InitStruct.Pin = GPIO_PIN_2|GPIO_PIN_8|GPIO_PIN_9;
  GPIO_InitStruct.Mode = GPIO_MODE_OUTPUT_PP;
  GPIO_InitStruct.Pull = GPIO_NOPULL;
  GPIO_InitStruct.Speed = GPIO_SPEED_FREQ_VERY_HIGH;
  HAL_GPIO_Init(GPIOC, &GPIO_InitStruct);

  /*Configure GPIO pins : PB12 PB14 */
  GPIO_InitStruct.Pin = GPIO_PIN_12|GPIO_PIN_14;
  GPIO_InitStruct.Mode = GPIO_MODE_OUTPUT_PP;
  GPIO_InitStruct.Pull = GPIO_NOPULL;
  GPIO_InitStruct.Speed = GPIO_SPEED_FREQ_VERY_HIGH;
  HAL_GPIO_Init(GPIOB, &GPIO_InitStruct);

  /*Configure GPIO pin : PA8 */
  GPIO_InitStruct.Pin = GPIO_PIN_8;
  GPIO_InitStruct.Mode = GPIO_MODE_OUTPUT_PP;
  GPIO_InitStruct.Pull = GPIO_NOPULL;
  GPIO_InitStruct.Speed = GPIO_SPEED_FREQ_LOW;
  HAL_GPIO_Init(GPIOA, &GPIO_InitStruct);

  /*Configure GPIO pin : PA15 */
  GPIO_InitStruct.Pin = GPIO_PIN_15;
  GPIO_InitStruct.Mode = GPIO_MODE_OUTPUT_PP;
  GPIO_InitStruct.Pull = GPIO_NOPULL;
  GPIO_InitStruct.Speed = GPIO_SPEED_FREQ_VERY_HIGH;
  HAL_GPIO_Init(GPIOA, &GPIO_InitStruct);

  /*Configure GPIO pin Output Level */
  HAL_GPIO_WritePin(GPIOC, GPIO_PIN_2, GPIO_PIN_SET);

  /*Configure GPIO pin Output Level */
  HAL_GPIO_WritePin(GPIOB, GPIO_PIN_12, GPIO_PIN_RESET);

  /*Configure GPIO pin Output Level */
  HAL_GPIO_WritePin(GPIOB, GPIO_PIN_14, GPIO_PIN_SET);

  /*Configure GPIO pin Output Level */
  HAL_GPIO_WritePin(GPIOC, GPIO_PIN_8|GPIO_PIN_9, GPIO_PIN_RESET);

  /*Configure GPIO pin Output Level */
  HAL_GPIO_WritePin(GPIOA, GPIO_PIN_8, GPIO_PIN_RESET);

  /*Configure GPIO pin Output Level */
  HAL_GPIO_WritePin(GPIOA, GPIO_PIN_15, GPIO_PIN_SET);

}

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


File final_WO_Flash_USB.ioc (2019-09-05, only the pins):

Mcu.UserName=STM32L476RGTx
PA15.Signal=GPIO_Output
PA2.Signal=USART2_TX
PA3.Signal=USART2_RX
PA4.Signal=ADCx_IN9
PA8.Signal=GPIO_Output
PB12.Signal=GPIO_Output
PB13.Signal=SPI2_SCK
PB14.Signal=GPIO_Output
PB15.Signal=SPI2_MOSI
PC0.Signal=GPIO_Input
PC10.Signal=SPI3_SCK
PC12.Signal=SPI3_MOSI
PC2.Signal=GPIO_Output
PC3.Signal=GPIO_Input
PC8.Signal=GPIO_Output
PC9.Signal=GPIO_Output

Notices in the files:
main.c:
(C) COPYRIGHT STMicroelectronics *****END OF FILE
